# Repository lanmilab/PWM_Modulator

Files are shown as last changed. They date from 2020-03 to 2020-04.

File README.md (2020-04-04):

# PWM_Modulator

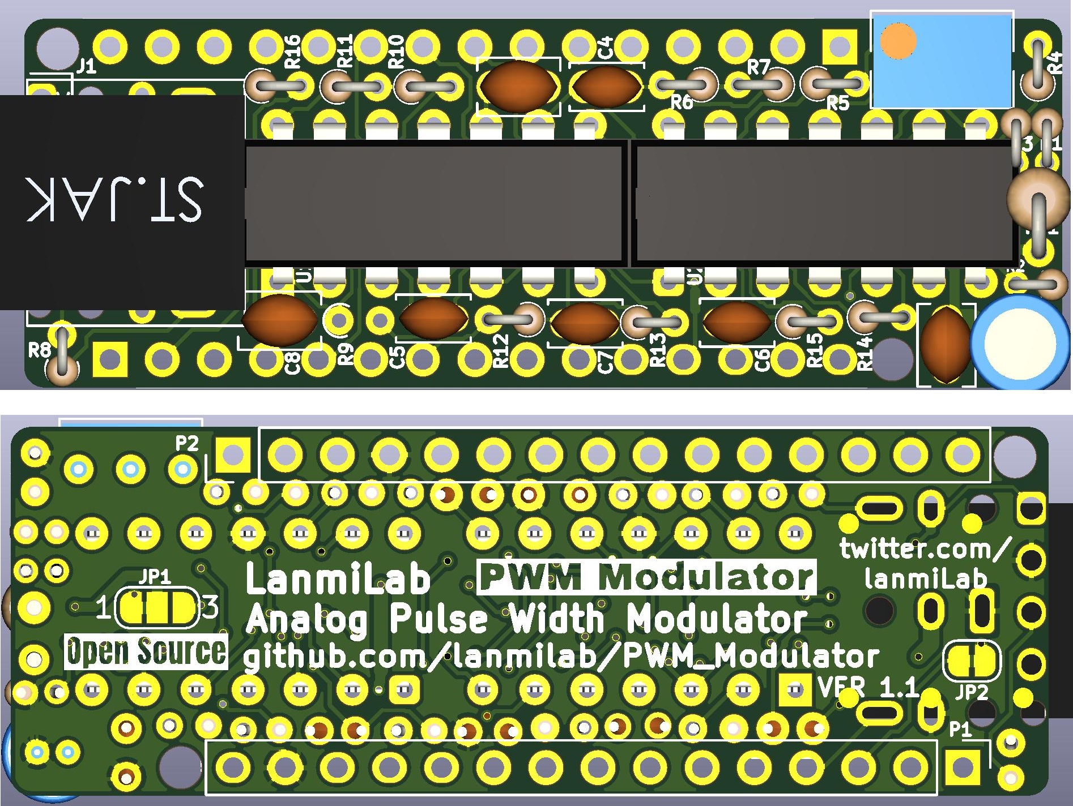
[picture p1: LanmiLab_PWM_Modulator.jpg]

Analog Pulse Width Modulator. Takes analog input signal like audio or ultrasound or DC voltage and modulates into differential output signal PWM1/PWM2 suitable for H-Bridge control. 

Applications:
  - Class D Audio Power Amplifier
  
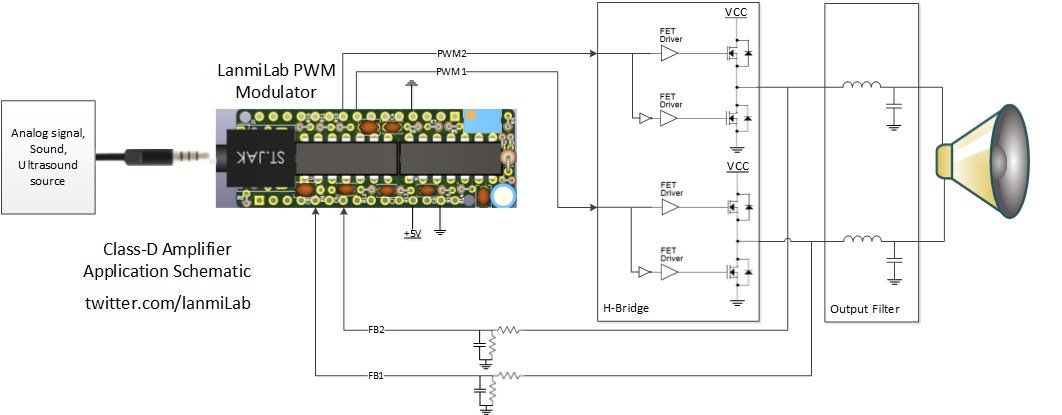
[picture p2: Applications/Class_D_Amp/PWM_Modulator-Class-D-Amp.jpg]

  
  - DC/DC power converter
  - LED Driver

## Signal Input Options
- **3.5mm Phono Jack J1.** This is suitable for connecting Audio signal source using Stereo Cable and 3.5mm male connector.
- **2.54mm Header J2.** Can be used to connect with another board as signal source like I2S DAC or Bluetooth Transceiver Module.
- **Potentiometer RV2.** In this case variable input is set via resistive potentiometer suitable for DC/DC  converter applications.
## Operation Modes
- **No Feedback.** R9 resistor should be populated and R15 unpopulated making feedback differential amplifier disconnected. Output pulse width is proportianal to input signal with default full scale input level of 1Vrms.
- **With Feedback.** Regulation is possible by closing negative Feedback circuit (see Class-D amplifier application) by populating R15 resistor and leaving R9 unpopulated. Feedback input connects to final regulation output (H-Bridge power stage output) through resistor divider network in order to adjust full scale of output (0-VCC) to full scale of input (1Vrms).
## Material
All parts listed in [LanmiLab_PWM_Modulator_BOM.csv](https://github.com/lanmilab/PWM_Modulator/blob/master/Production/Assembly/LanmiLab_PWM_Modulator_BOM.csv "LanmiLab_PWM_Modulator_BOM.csv"). Or use Application specific BOM from [PWM_Modulator](https://github.com/lanmilab/PWM_Modulator)/**Applications**/.
## PCB Fabrication
Send [LanmiLab_PWM_Modulator_gerbers.zip](https://github.com/lanmilab/PWM_Modulator/blob/master/Production/PCB/LanmiLab_PWM_Modulator_gerbers.zip "LanmiLab_PWM_Modulator_gerbers.zip") fabrication files to PCB Manufacturer.
## Assembly
Download and use [ibom.html](https://github.com/lanmilab/PWM_Modulator/blob/master/Production/Assembly/ibom.html "ibom.html") as soldering guide.
## Setting Frequency
Use Trimpot **RV1** to set desired PWM frequency. If oscilloscope is available use it to measure CLOCKOUT signal at P2 pin 10, otherwise use multimeter to measure RV1 resistance (between pins 1-2) and calculate frequency according:
> F=R7/(R6*(RV1+R5)*C)/4.

<a href="https://twitter.com/lanmiLab">twitter.com/lanmiLab</a>

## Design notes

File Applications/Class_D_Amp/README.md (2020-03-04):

Building Class-D Amplifier using PWM_Modulator Board

Image description

<a href="https://twitter.com/lanmiLab">twitter.com/lanmiLab</a>

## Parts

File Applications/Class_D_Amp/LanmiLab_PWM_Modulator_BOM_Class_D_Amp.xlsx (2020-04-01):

Reference | Quantity | Value | Part Number Farnell | Part Number Mouser | Note
C1 | 1 | 47uF | ECEA0JKA470 (https://uk.farnell.com/panasonic/ecea0jka470/cap-47-f-6-3v-20/dp/1902034?st=ECEA0JKA470) | ECE-A0JKA470 (https://eu.mouser.com/ProductDetail/Panasonic/ECE-A0JKA470)
C3 C2 C8 | 3 | 1uF/25V | C315C105K3R5TA (https://uk.farnell.com/kemet/c315c105k3r5ta/cap-1-f-25v-10-x7r/dp/2819619) | C315C105K3R5TA (https://eu.mouser.com/ProductDetail/KEMET/C315C105K3R5TA)
C5 C7 C4 C6 | 4 | 68pF/5%/C0G | K680J15C0GF53L2 (https://uk.farnell.com/vishay/k680j15c0gf53l2/cap-68pf-50v-5-c0g-np0/dp/1141763) | K680J15C0GF5TL2 (https://eu.mouser.com/ProductDetail/Vishay-BC-Components/K680J15C0GF5TL2)
FB1 | 1 | Ferrite_Bead | BL02RN1R2M2B (https://uk.farnell.com/murata/bl02rn1r2m2b/filter-emi-7a-radial-single/dp/9526838) | BL02RN1R2M2B (https://eu.mouser.com/ProductDetail/Murata-Electronics/BL02RN1R2M2B)
J1 | 1 | AudioJack3 | FC68131 (https://uk.farnell.com/cliff-electronic-components/fc68131/stereo-jack-3-5mm-3pos-pcb/dp/2518188) | SJ1-3523N (https://eu.mouser.com/ProductDetail/CUI-Devices/SJ1-3523N)
P1 P2 | 2 | Conn_01x15 | 61301511121 (https://uk.farnell.com/wurth-elektronik/61301511121/header-2-54mm-pin-tht-vert-15way/dp/2356165) | 61301511121 (https://eu.mouser.com/ProductDetail/Wurth-Elektronik/61301511121)
R12 R13 R4 R3 R10 R11 R8 R16 | 8 | 47K | LR0204F47K (https://uk.farnell.com/te-connectivity/lr0204f47k/res-47k-1-250mw-axial-metal-film/dp/2329944) | MFR-12FTF52-47K (https://eu.mouser.com/ProductDetail/Yageo/MFR-12FTF52-47K?qs=sGAEpiMZZMu61qfTUdNhG0IXHLFuiNndnEnKYY3JKJk%3D)
R5 R2 R1 | 3 | 2K2 | LR0204F2K2 (https://uk.farnell.com/te-connectivity/lr0204f2k2/res-2k2-1-250mw-axial-metal-film/dp/2329912) | LR0204F2K2 (https://eu.mouser.com/ProductDetail/TE-Connectivity-Neohm/LR0204F2K2)
R6 R15 R14 R9 | 4 | 23K7 | MRS25000C2372FCT00 (https://uk.farnell.com/vishay/mrs25000c2372fct00/res-23k7-1-600mw-axial-metal-film/dp/9466207) | MRS25000C2372FCT00 (https://eu.mouser.com/ProductDetail/Vishay-BC-Components/MRS25000C2372FCT00) | R9 Not populated in Feedback variant, R15 Not populated in No Feedback variant
R7 | 1 | 62K | LR0204F62K (https://uk.farnell.com/te-connectivity/lr0204f62k/res-62k-1-250mw-axial-metal-film/dp/2329961) | LR0204F62K (https://eu.mouser.com/ProductDetail/TE-Connectivity-Neohm/LR0204F62K)
RV1 | 1 | Trimpot 12 turns | 3266W-1-104LF (https://uk.farnell.com/bourns/3266w-1-104lf/pot-trimmer-100k-12-turn-3-pin/dp/9352660) | 3266W-1-104LF (https://eu.mouser.com/ProductDetail/Bourns/3266W-1-104LF?qs=sGAEpiMZZMvygUB3GLcD7rufck0TIBKyeLzadjsfIz4%3D)
U1 | 1 | Quad Opamp | LM6144BIN/NOPB (https://uk.farnell.com/texas-instruments/lm6144bin-nopb/op-amp-quad-17mhz-rri-o-6144-dip/dp/3004647) | LM6144BIN/NOPB (https://eu.mouser.com/ProductDetail/Texas-Instruments/LM6144BIN-NOPB)
U2 | 1 | Quad Comparator | MAX944CPD+ (https://uk.farnell.com/maxim-integrated-products/max944cpd/comparator-0-to-70deg-c-dip-14/dp/3257474) | MAX944CPD+ (https://eu.mouser.com/ProductDetail/Maxim-Integrated/MAX944CPD%2b)

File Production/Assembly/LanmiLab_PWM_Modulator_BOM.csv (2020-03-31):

Reference | Quantity | Value | Footprint | Datasheet | Part Number | Note
C1 | 1 | 47uF | Capacitor_THT:C_Radial_D4.0mm_H7.0mm_P1.50mm | http://industrial.panasonic.com/cdbs/www-data/pdf/RDF0000/ABA0000C1050.pdf | ECEA0JKA470
C3 C2 C8 | 3 | 1uF/25V | Capacitor_THT:C_Disc_D3.8mm_W2.6mm_P2.50mm | http://www.farnell.com/datasheets/2738428.pdf | C315C105K3R5TA
C5 C7 C4 C6 | 4 | 68pF/5%/C0G | Capacitor_THT:C_Disc_D3.4mm_W2.1mm_P2.50mm | http://www.farnell.com/datasheets/2045792.pdf | K680J15C0GF53L2
FB1 | 1 | Ferrite_Bead | Resistor_THT:R_Axial_DIN0309_L9.0mm_D3.2mm_P2.54mm_Vertical | http://www.farnell.com/datasheets/2048185.pdf | BL02RN1R2M2B
J1 | 1 | AudioJack3 | Jack:FC68131CLIFF | http://www.farnell.com/datasheets/2028381.pdf | FC68131
J2 | 1 | Header 1X4 | Connector_PinHeader_2.54mm:PinHeader_1x04_P2.54mm_Vertical | ~ |  | For Breakout/Module
JP1 | 1 | SolderJumper_3_Bridged12 | Jumper:SolderJumper-3_P1.3mm_Bridged12_RoundedPad1.0x1.5mm_NumberLabels | ~ |  | Not Populated, Configuration Jumper
JP2 | 1 | SolderJumper_2_Bridged | Jumper:SolderJumper-2_P1.3mm_Bridged_RoundedPad1.0x1.5mm | ~ |  | Not Populated, Configuration Jumper
P1 P2 | 2 | Conn_01x15 | Connector_PinHeader_2.54mm:PinHeader_1x15_P2.54mm_Vertical | https://www.we-online.de/katalog/datasheet/6130xx11121.pdf | 61301511121
R12 R13 R4 R3 R10 R11 R8 R16 | 8 | 47K | Resistor_THT:R_Axial_DIN0204_L3.6mm_D1.6mm_P1.90mm_Vertical | https://www.te.com/commerce/DocumentDelivery/DDEController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 | LR0204F47K
R5 R2 R1 | 3 | 2K2 | Resistor_THT:R_Axial_DIN0204_L3.6mm_D1.6mm_P1.90mm_Vertical | http://www.farnell.com/datasheets/1723855.pdf | LR0204F2K2
R6 R15 R14 R9 | 4 | 23K7 | Resistor_THT:R_Axial_DIN0204_L3.6mm_D1.6mm_P1.90mm_Vertical | http://www.farnell.com/datasheets/2046132.pdf | MRS25000C2372FCT00
R7 | 1 | 62K | Resistor_THT:R_Axial_DIN0204_L3.6mm_D1.6mm_P1.90mm_Vertical | http://www.farnell.com/datasheets/2710513.pdf | LR0204F62K
RV1 | 1 | Trimpot 12 turns | Potentiometer_THT:Potentiometer_Bourns_3266Y_Vertical | http://www.farnell.com/datasheets/2061259.pdf | 3266W-1-104LF
RV2 | 1 | R_POT_Small | Potentiometer_THT:Potentiometer_Omeg_PC16BU_Horizontal | http://www.farnell.com/datasheets/1727905.pdf | PDB181-K220K-103B
U1 | 1 | Quad Opamp | Package_DIP:DIP-14_W7.62mm | https://www.ti.com/lit/ds/symlink/lm6144.pdf | LM6144BIN/NOPB
U2 | 1 | Quad Comparator | Package_DIP:DIP-14_W7.62mm | https://datasheets.maximintegrated.com/en/ds/MAX941-MAX944.pdf | MAX944CPD+

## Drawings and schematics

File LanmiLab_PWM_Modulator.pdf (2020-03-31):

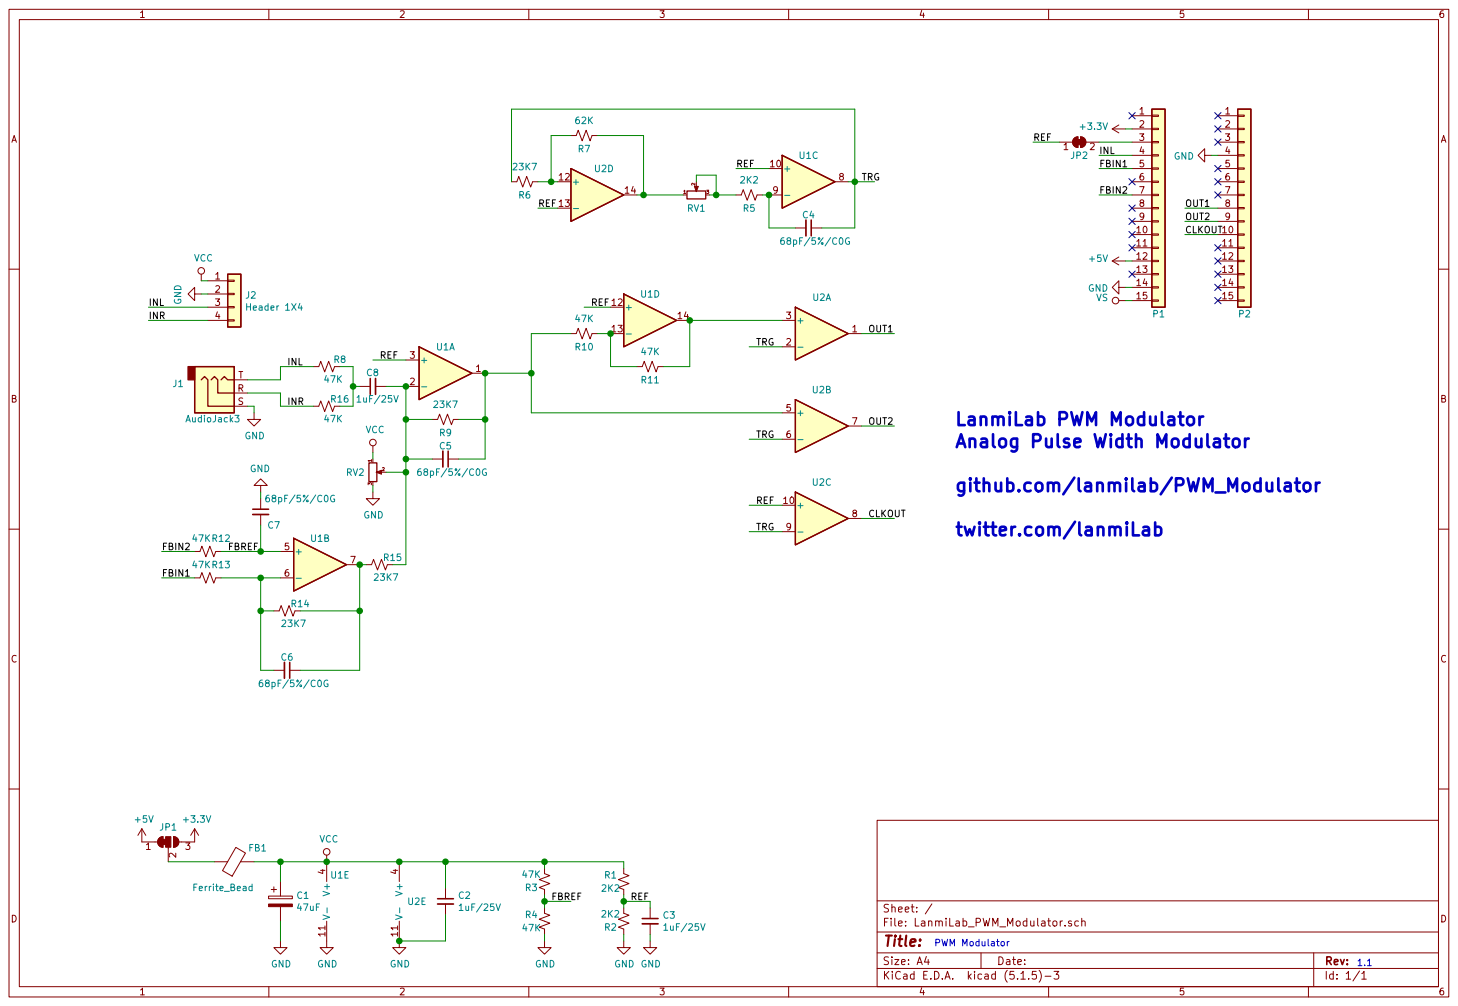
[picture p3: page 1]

Analog Pulse Width Modulator

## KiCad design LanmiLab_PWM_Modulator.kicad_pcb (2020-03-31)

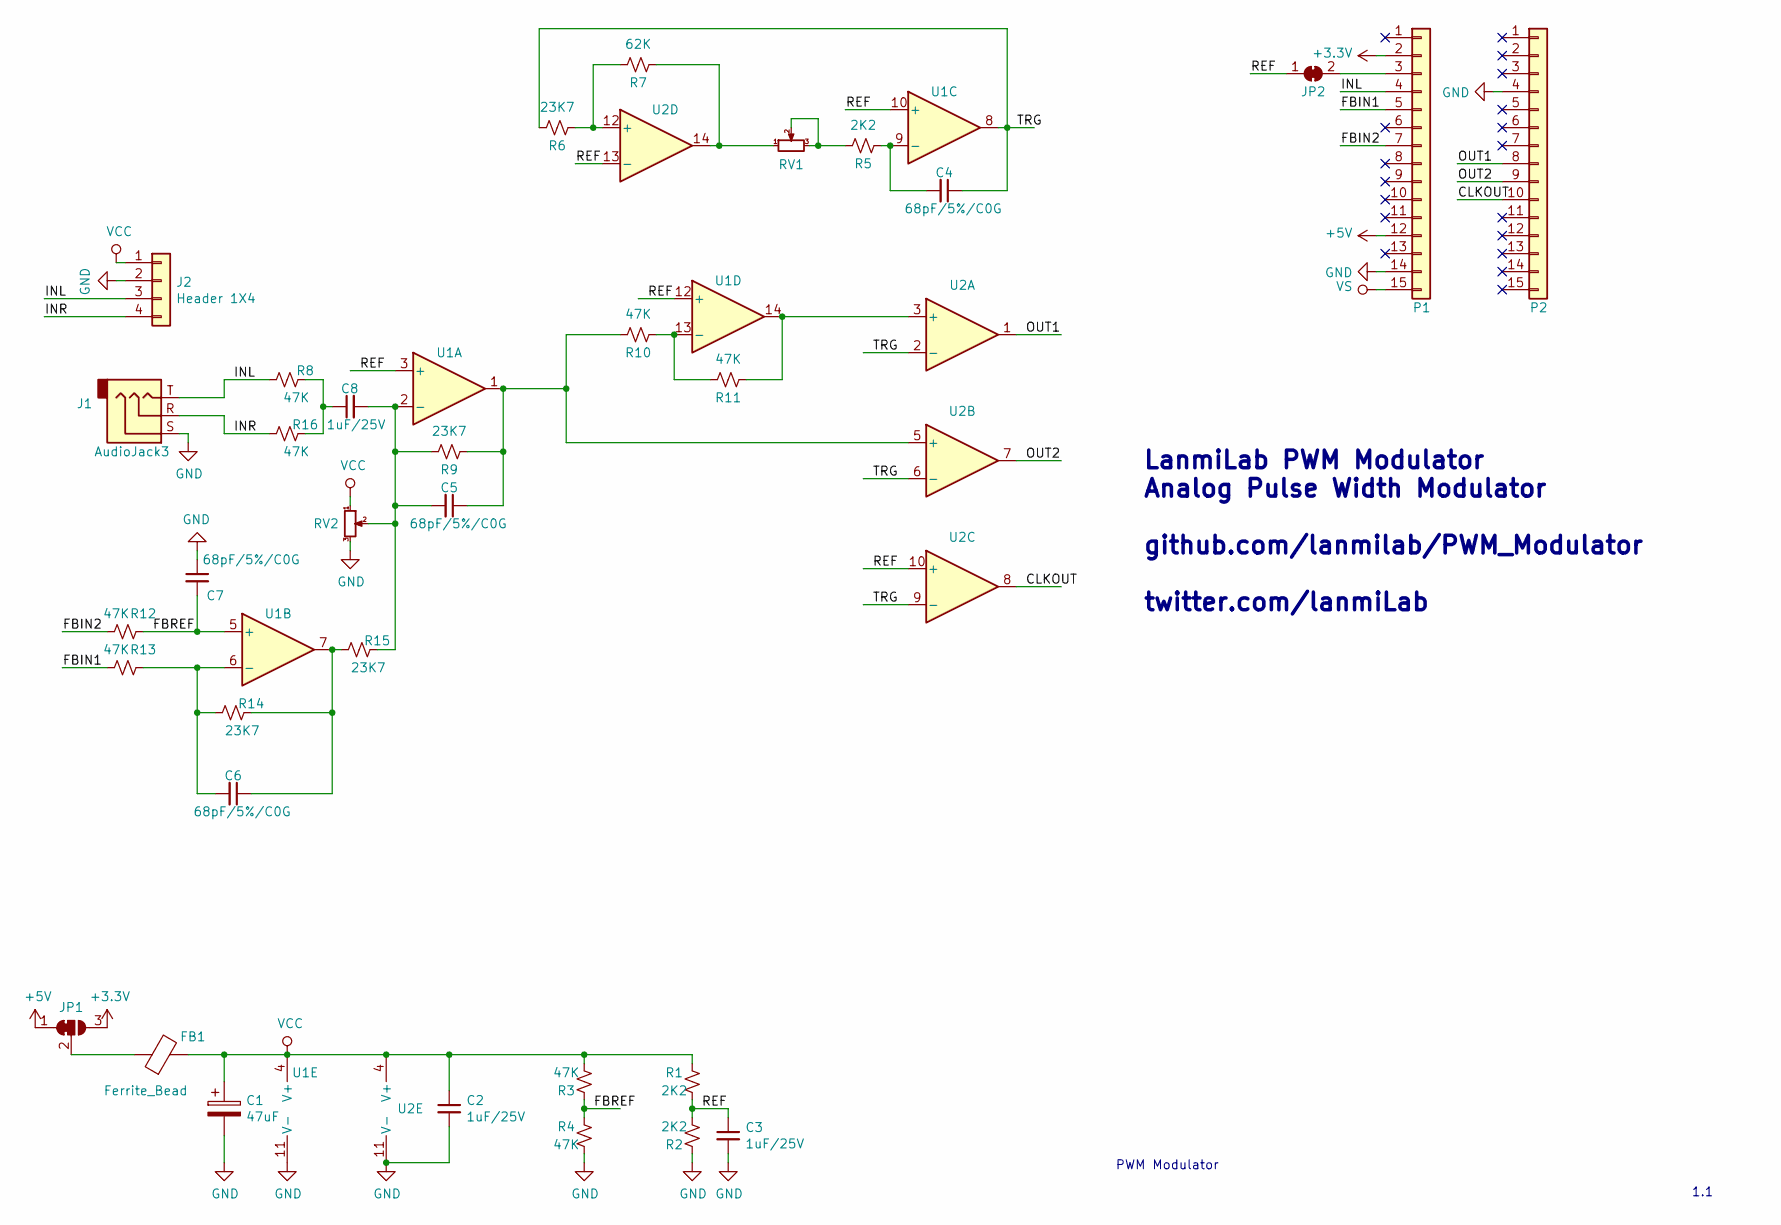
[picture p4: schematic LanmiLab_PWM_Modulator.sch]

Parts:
C1: 47uF; C_Radial_D4.0mm_H7.0mm_P1.50mm; Part Number ECEA0JKA470
C2, C3, C8: 1uF/25V; C_Disc_D3.8mm_W2.6mm_P2.50mm; Part Number C315C105K3R5TA
C4, C5, C6, C7: 68pF/5%/C0G; C_Disc_D3.4mm_W2.1mm_P2.50mm; Part Number K680J15C0GF53L2
FB1: Ferrite_Bead; R_Axial_DIN0309_L9.0mm_D3.2mm_P2.54mm_Vertical; Part Number BL02RN1R2M2B
J1: AudioJack3; FC68131CLIFF; Part Number FC68131
J2: Header 1X4; PinHeader_1x04_P2.54mm_Vertical
JP1: SolderJumper_3_Bridged12; SolderJumper-3_P1.3mm_Bridged12_RoundedPad1.0x1.5mm_NumberL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
JP2: SolderJumper_2_Bridged; SolderJumper-2_P1.3mm_Bridged_RoundedPad1.0x1.5mm
P1, P2: Conn_01x15; PinHeader_1x15_P2.54mm_Vertical; Part Number 61301511121
R1, R2, R5: 2K2; R_Axial_DIN0204_L3.6mm_D1.6mm_P1.90mm_Vertical; Part Number LR0204F2K2
R3, R4, R8, R10, R11, R12, R13, R16: 47K; R_Axial_DIN0204_L3.6mm_D1.6mm_P1.90mm_Vertical; Part Number LR0204F47K
R6, R9: 23K7; R_Axial_DIN0204_L3.6mm_D1.6mm_P1.90mm_Vertical; Part Number MRS25000C2372FCT00
R7: 62K; R_Axial_DIN0204_L3.6mm_D1.6mm_P1.90mm_Vertical; Part Number LR0204F62K
R14, R15: 23K7; R_Axial_DIN0204_L3.6mm_D1.6mm_P1.90mm_Vertical; Part Number MRS25000C3092FCT00
RV1: Trimpot 12 turns; Potentiometer_Bourns_3266Y_Vertical; Part Number 3266W-1-104LF
RV2: R_POT_Small; Potentiometer_Omeg_PC16BU_Horizontal; Part Number PDB181-K220K-103B
U1: Quad Opamp; DIP-14_W7.62mm; Part Number LM6144BIN/NOPB
U2: Quad Comparator; DIP-14_W7.62mm; Part Number MAX944CPD+

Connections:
+3V3: JP1.3 (B), P1.2
+5V: JP1.1 (A), P1.12
/CLKOUT: P2.10, U2.8
/FBIN1: P1.5, R13.2
/FBIN2: P1.7, R12.2
/FBREF: C7.2, R3.1, R4.1, R12.1, U1.5 (+)
/INL: J1.T, J2.3, P1.4, R8.1
/INR: J1.R, J2.4, R16.1
/OUT1: P2.8, U2.1
/OUT2: P2.9, U2.7
/REF: C3.1, JP2.1 (A), R1.2, R2.2, U1.3 (+), U1.10 (+), U1.12 (+), U2.10 (+), U2.13 (-)
/TRG: C4.1, R6.2, U1.8, U2.2 (-), U2.6 (-), U2.9 (-)
GND: C1.2, C2.2, C3.2, C7.1, J1.S, J2.2, P1.14, P2.4, R2.1, R4.2, RV2.3, U1.11 (V-), U2.11 (V-)
unnamed: C4.2, R5.1, U1.9 (-)
unnamed: C5.1, R9.1, R10.2, U1.1, U2.5 (+)
unnamed: C5.2, C8.2, R9.2, R15.2, RV2.2, U1.2 (-)
unnamed: C6.1, R14.2, R15.1, U1.7
unnamed: C6.2, R13.1, R14.1, U1.6 (-)
unnamed: C8.1, R8.2, R16.2
unnamed: FB1.1, JP1.2 (C)
unnamed: JP2.2 (B), P1.3
unnamed: R5.2, RV1.2, RV1.3
unnamed: R6.1, R7.2, U2.12 (+)
unnamed: R7.1, RV1.1, U2.14
unnamed: R10.1, R11.2, U1.13 (-)
unnamed: R11.1, U1.14, U2.3 (+)
VCC: C1.1, C2.1, FB1.2, J2.1, R1.1, R3.2, RV2.1, U1.4 (V+), U2.4 (V+)
VS: P1.15

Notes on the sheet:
PWM Modulator
1.1
LanmiLab PWM Modulator Analog Pulse Width Modulator github.com/lanmilab/PWM_Modulator twitter.com/lanmiLab

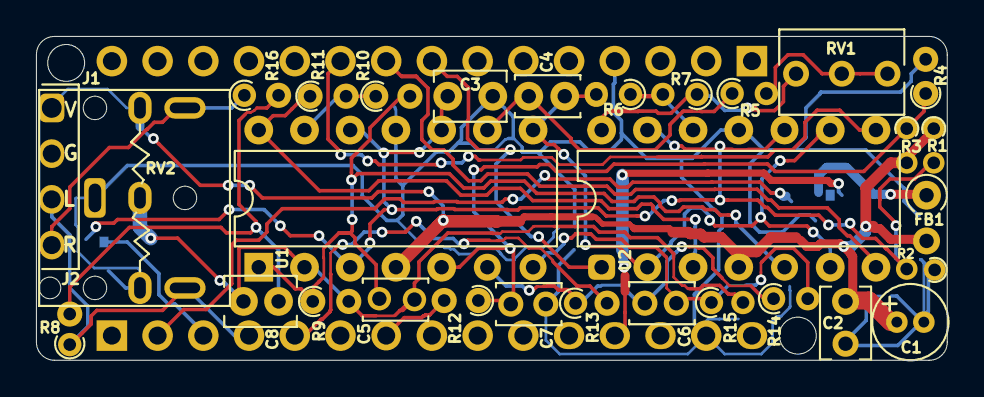
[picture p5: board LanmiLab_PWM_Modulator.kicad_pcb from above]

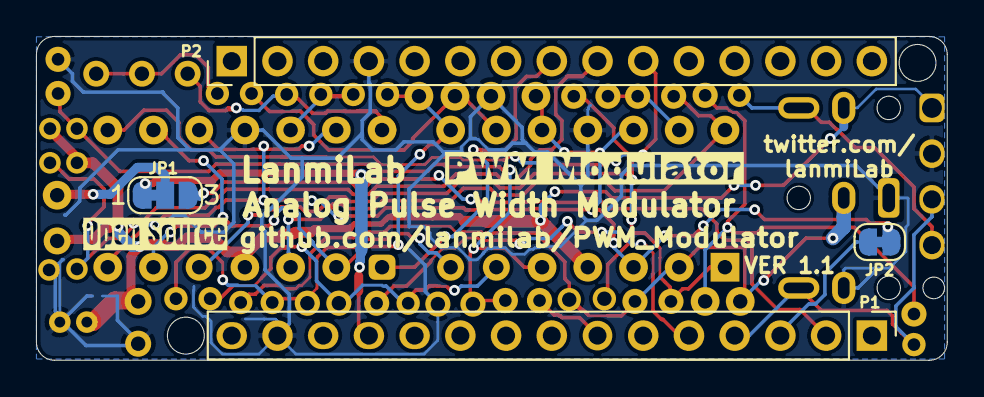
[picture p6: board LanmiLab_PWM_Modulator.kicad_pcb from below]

Board: 2 copper layers, 50.6 x 18.0 mm, 35 parts (4 on the bottom side), 27 nets.

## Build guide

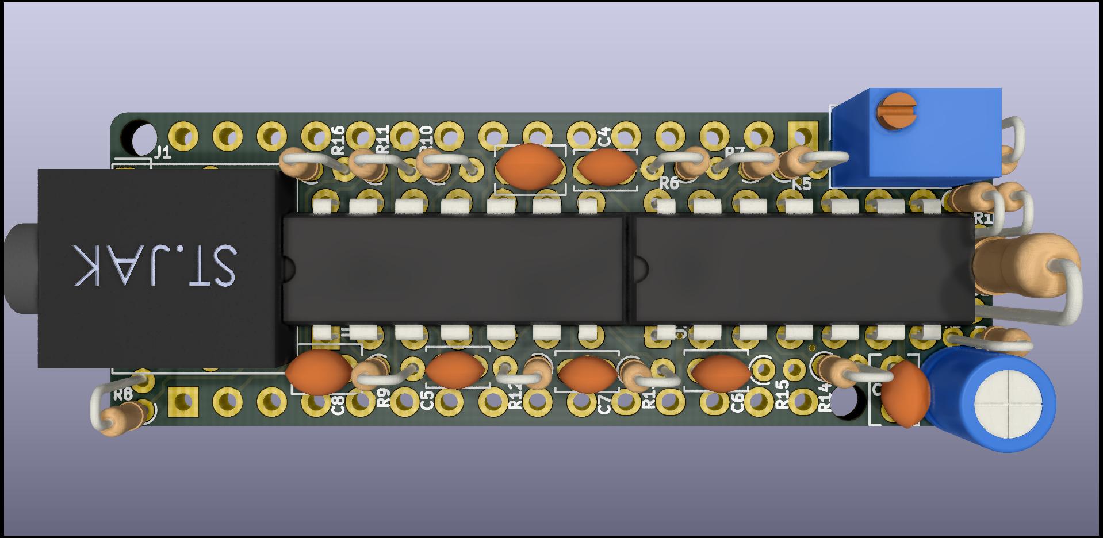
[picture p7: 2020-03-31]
Production/Assembly/LanmiLab_PWM_Modulator_Realistic_Top.jpg

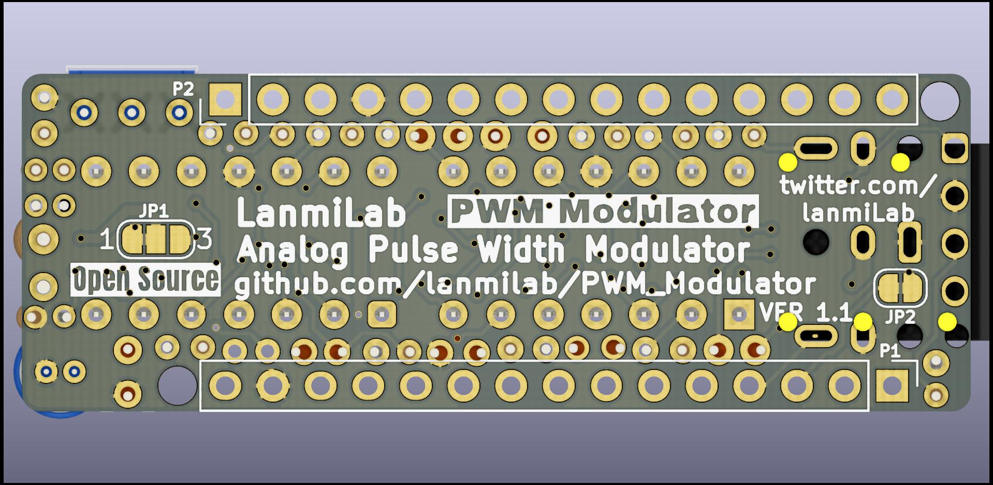
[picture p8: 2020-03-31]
Production/Assembly/LanmiLab_PWM_Modulator_Realistic_Bottom.jpg

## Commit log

2020-03-04 Update with application diagram for Class D Power Amplifier
2020-03-31 Gerbers Version 1.1 update
2020-03-31 Version 1.1 Update
    [LanmiLab_PWM_Modulator_BOM.csv]
2020-03-31 Version 1.1 Update
    Update to version 1.1 based on first prototype test.
    [LanmiLab_PWM_Modulator.kicad_pcb, LanmiLab_PWM_Modulator.sch]
2020-04-01 Part list for Class-D Amp Application
    [LanmiLab_PWM_Modulator_BOM_Class_D_Amp.xlsx]
